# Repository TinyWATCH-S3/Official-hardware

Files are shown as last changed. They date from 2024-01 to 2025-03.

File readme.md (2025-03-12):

# TinyWATCH-S3 Official Hardware

In this repository, you will find all of the KiCAD design files for the official Unexpected Maker TinyWATCH-S3

**The current release version of the TinyWATCH S3 hardware is revision P10.**

Please note that the license for these design files is the CERN Open Hardware Licence v1.2, which requires any use of these design files to be also kept fully open source under the same license.

So though you are free to use these files in your own projects, and even commercialise them, the "thing" you make must be open source and shared with the community.

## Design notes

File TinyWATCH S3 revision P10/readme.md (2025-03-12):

# TinyWATCH-S3 revision P10

I've made my best efforts to ensure consistency between the PCB layout and Schematic in terms of component values and packages.

Many footprints in the design reference non-standard (library) footprints, and I don't offer a library for them as they are already embedded in PCB layout anyway. 

If you do find any other inconsistencies, please create a PR, or raise an issue, thanks :)

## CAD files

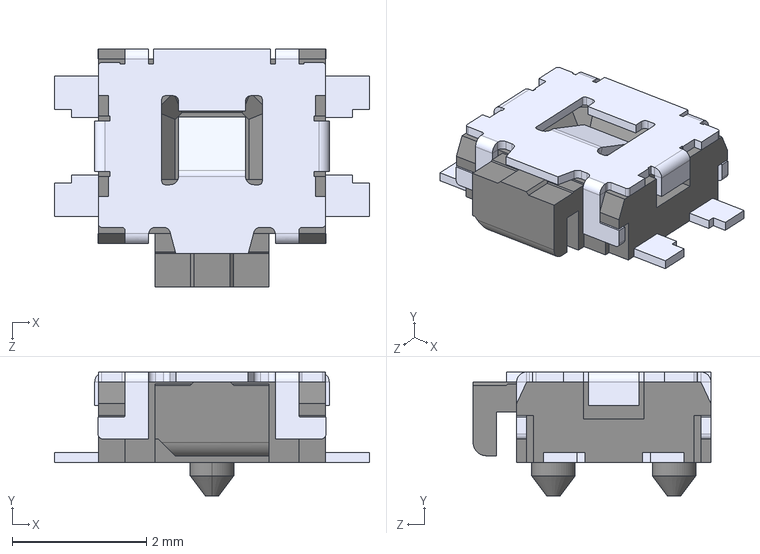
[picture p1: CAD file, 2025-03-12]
TinyWATCH S3 revision P10/KiCAD 8.09/3d_models/EVQ-P7C01P.step
4.70 x 1.85 x 3.55 mm

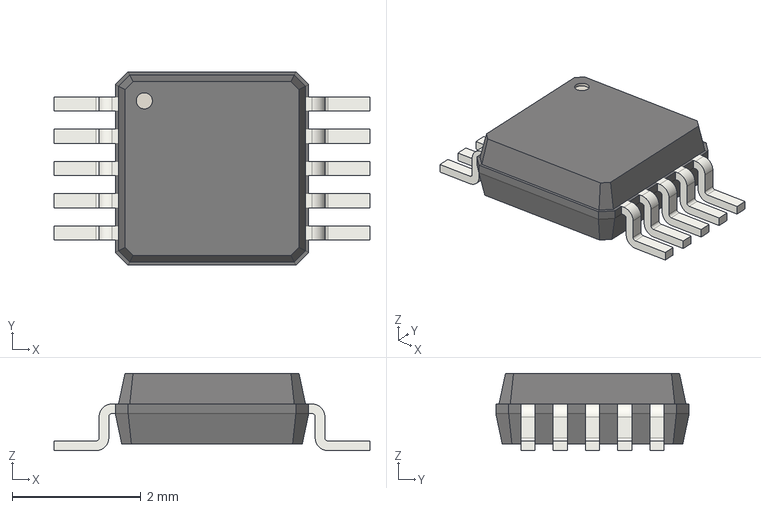
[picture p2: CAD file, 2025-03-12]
TinyWATCH S3 revision P7/KiCAD 8.09/3d_models/VSSOP-10_3x3mm_P0.5mm.step
4.90 x 3.00 x 1.20 mm

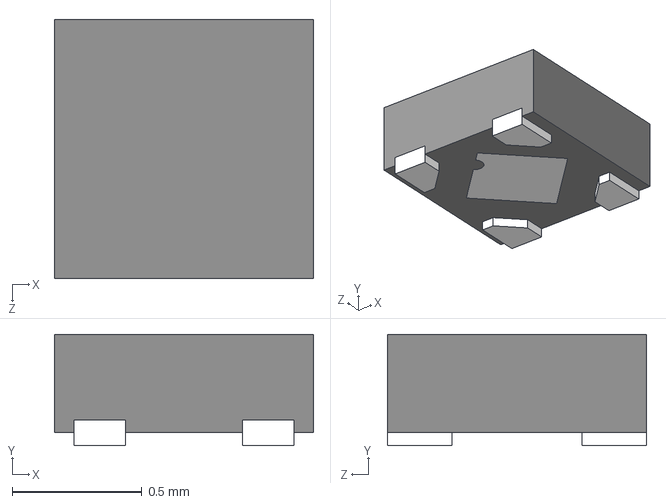
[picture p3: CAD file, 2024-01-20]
TinyWATCH S3 revision P7/KiCAD 8.09/3d_models/NCP170AMX170TCG.STEP
1.00 x 0.43 x 1.00 mm

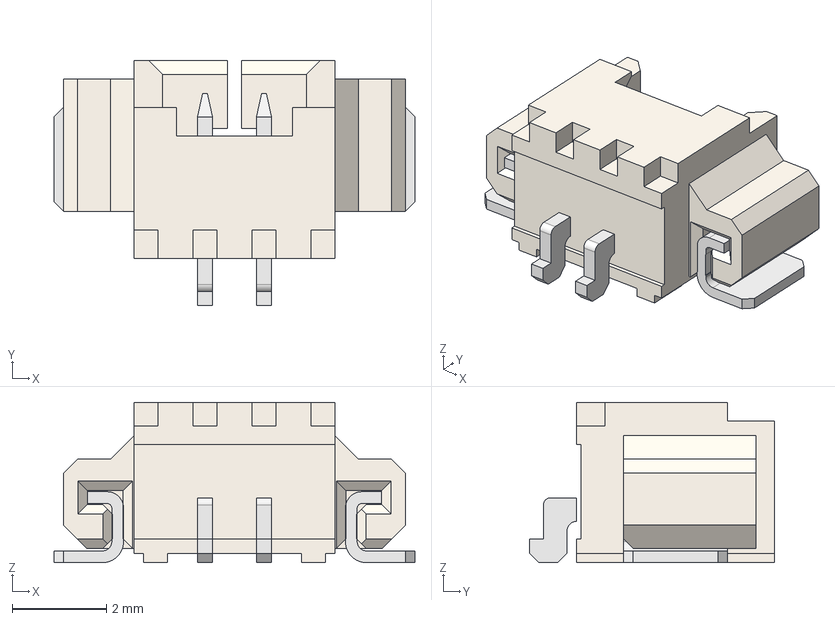
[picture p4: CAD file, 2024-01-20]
TinyWATCH S3 revision P7/KiCAD 8.09/3d_models/PICOBLADE Col v3.step
7.65 x 5.20 x 3.40 mm

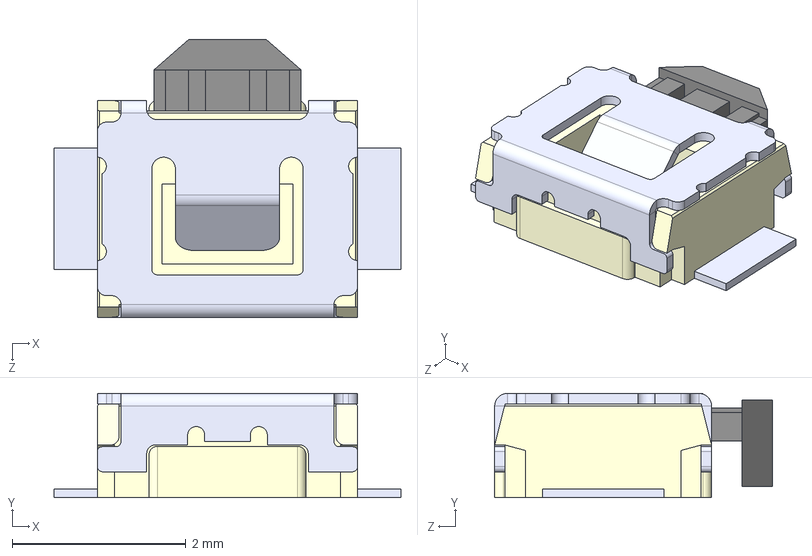
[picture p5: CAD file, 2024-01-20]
TinyWATCH S3 revision P10/KiCAD 8.09/3d_models/B3U-3000P--3DModel-STEP-56544.STEP
4.00 x 1.20 x 3.20 mm

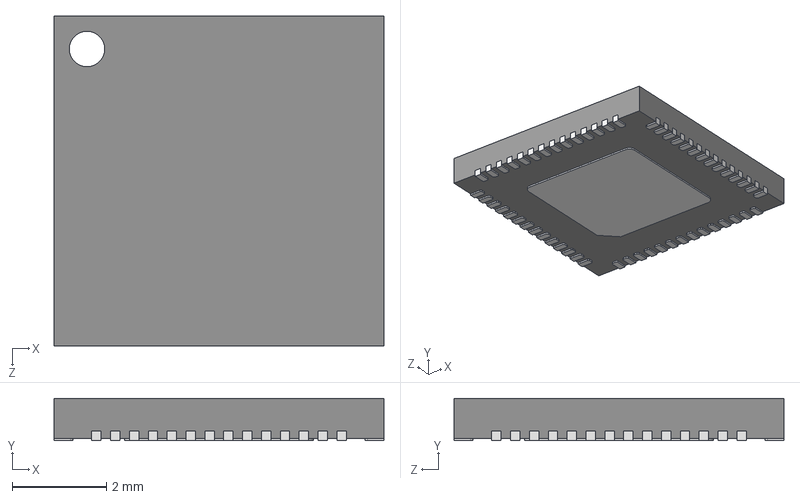
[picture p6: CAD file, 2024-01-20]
TinyWATCH S3 revision P7/KiCAD 8.09/3d_models/ESP32_S2--3DModel-STEP-1.STEP
7.00 x 0.9 x 7.00 mm

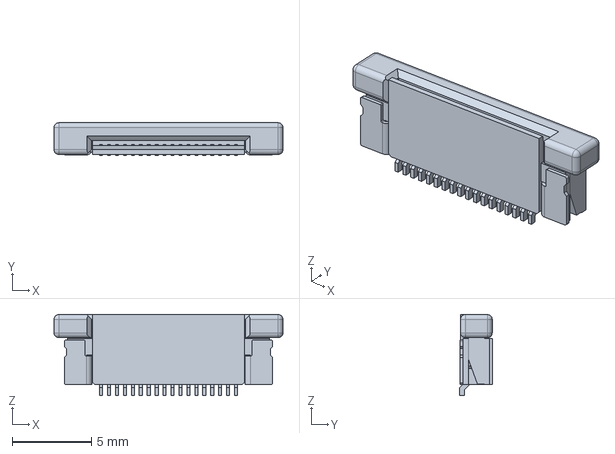
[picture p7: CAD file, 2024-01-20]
TinyWATCH S3 revision P10/KiCAD 8.09/3d_models/FPC_18pin_0.5mm_1-1734592-8.stp
14.4 x 2.05 x 5.11 mm

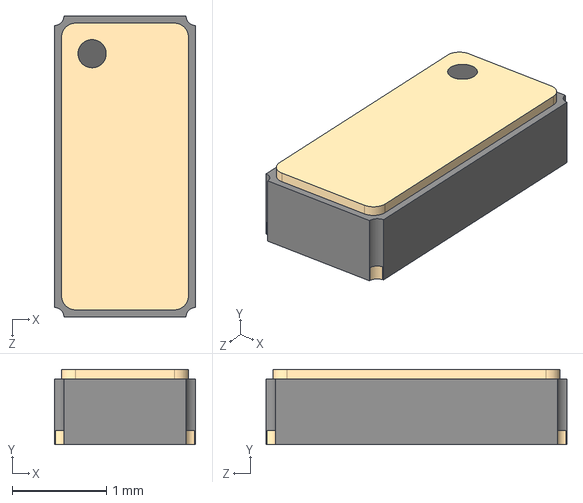
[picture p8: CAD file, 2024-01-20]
TinyWATCH S3 revision P7/KiCAD 8.09/3d_models/RV-3028-C7-32.768KHZ-1PPM-TA-QA.step
1.50 x 0.8 x 3.20 mm

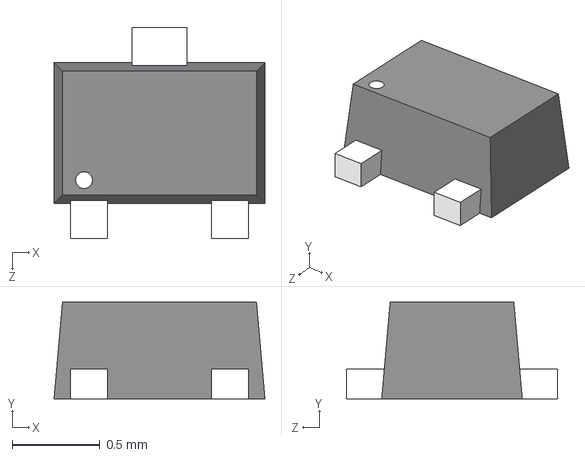
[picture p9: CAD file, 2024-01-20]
TinyWATCH S3 revision P10/KiCAD 8.09/3d_models/SOT-723.STEP
1.20 x 0.55 x 1.20 mm

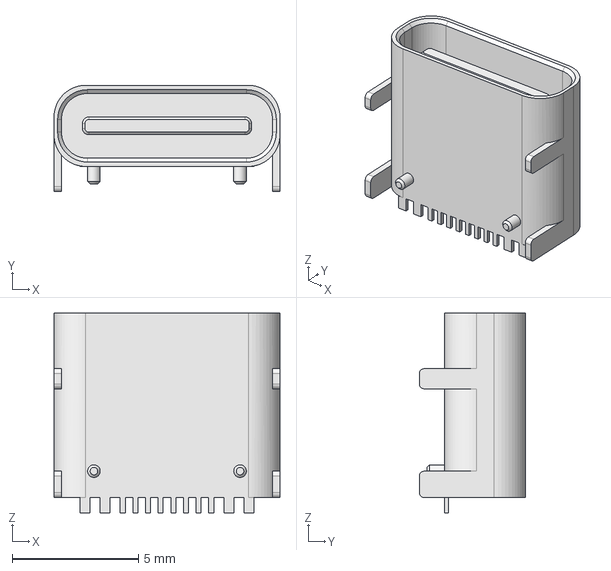
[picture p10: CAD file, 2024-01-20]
TinyWATCH S3 revision P10/KiCAD 8.09/3d_models/HRO USB-C col 3 v5.step
8.94 x 4.21 x 7.90 mm

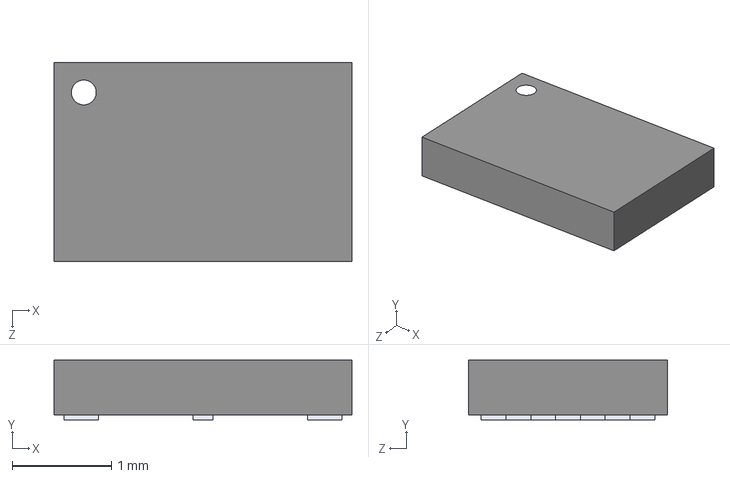
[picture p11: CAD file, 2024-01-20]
TinyWATCH S3 revision P10/KiCAD 8.09/3d_models/Flash_W25Q80DVUXIE.step
3.00 x 0.6 x 2.00 mm

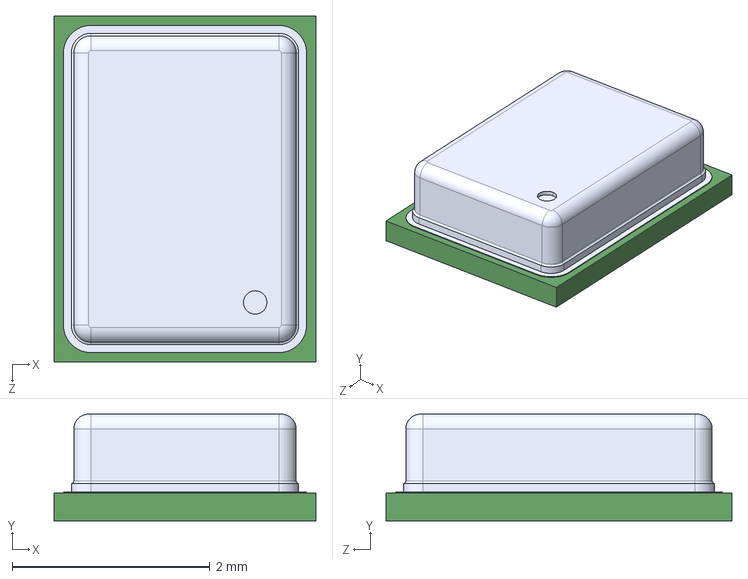
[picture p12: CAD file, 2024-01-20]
TinyWATCH S3 revision P7/KiCAD 8.09/3d_models/SPH0645LM4H-B--3DModel-STEP-56544.STEP
2.65 x 1.08 x 3.50 mm

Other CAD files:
TinyWATCH S3 revision P10/KiCAD 8.09/3d_models/SMD_Nut_M2.step

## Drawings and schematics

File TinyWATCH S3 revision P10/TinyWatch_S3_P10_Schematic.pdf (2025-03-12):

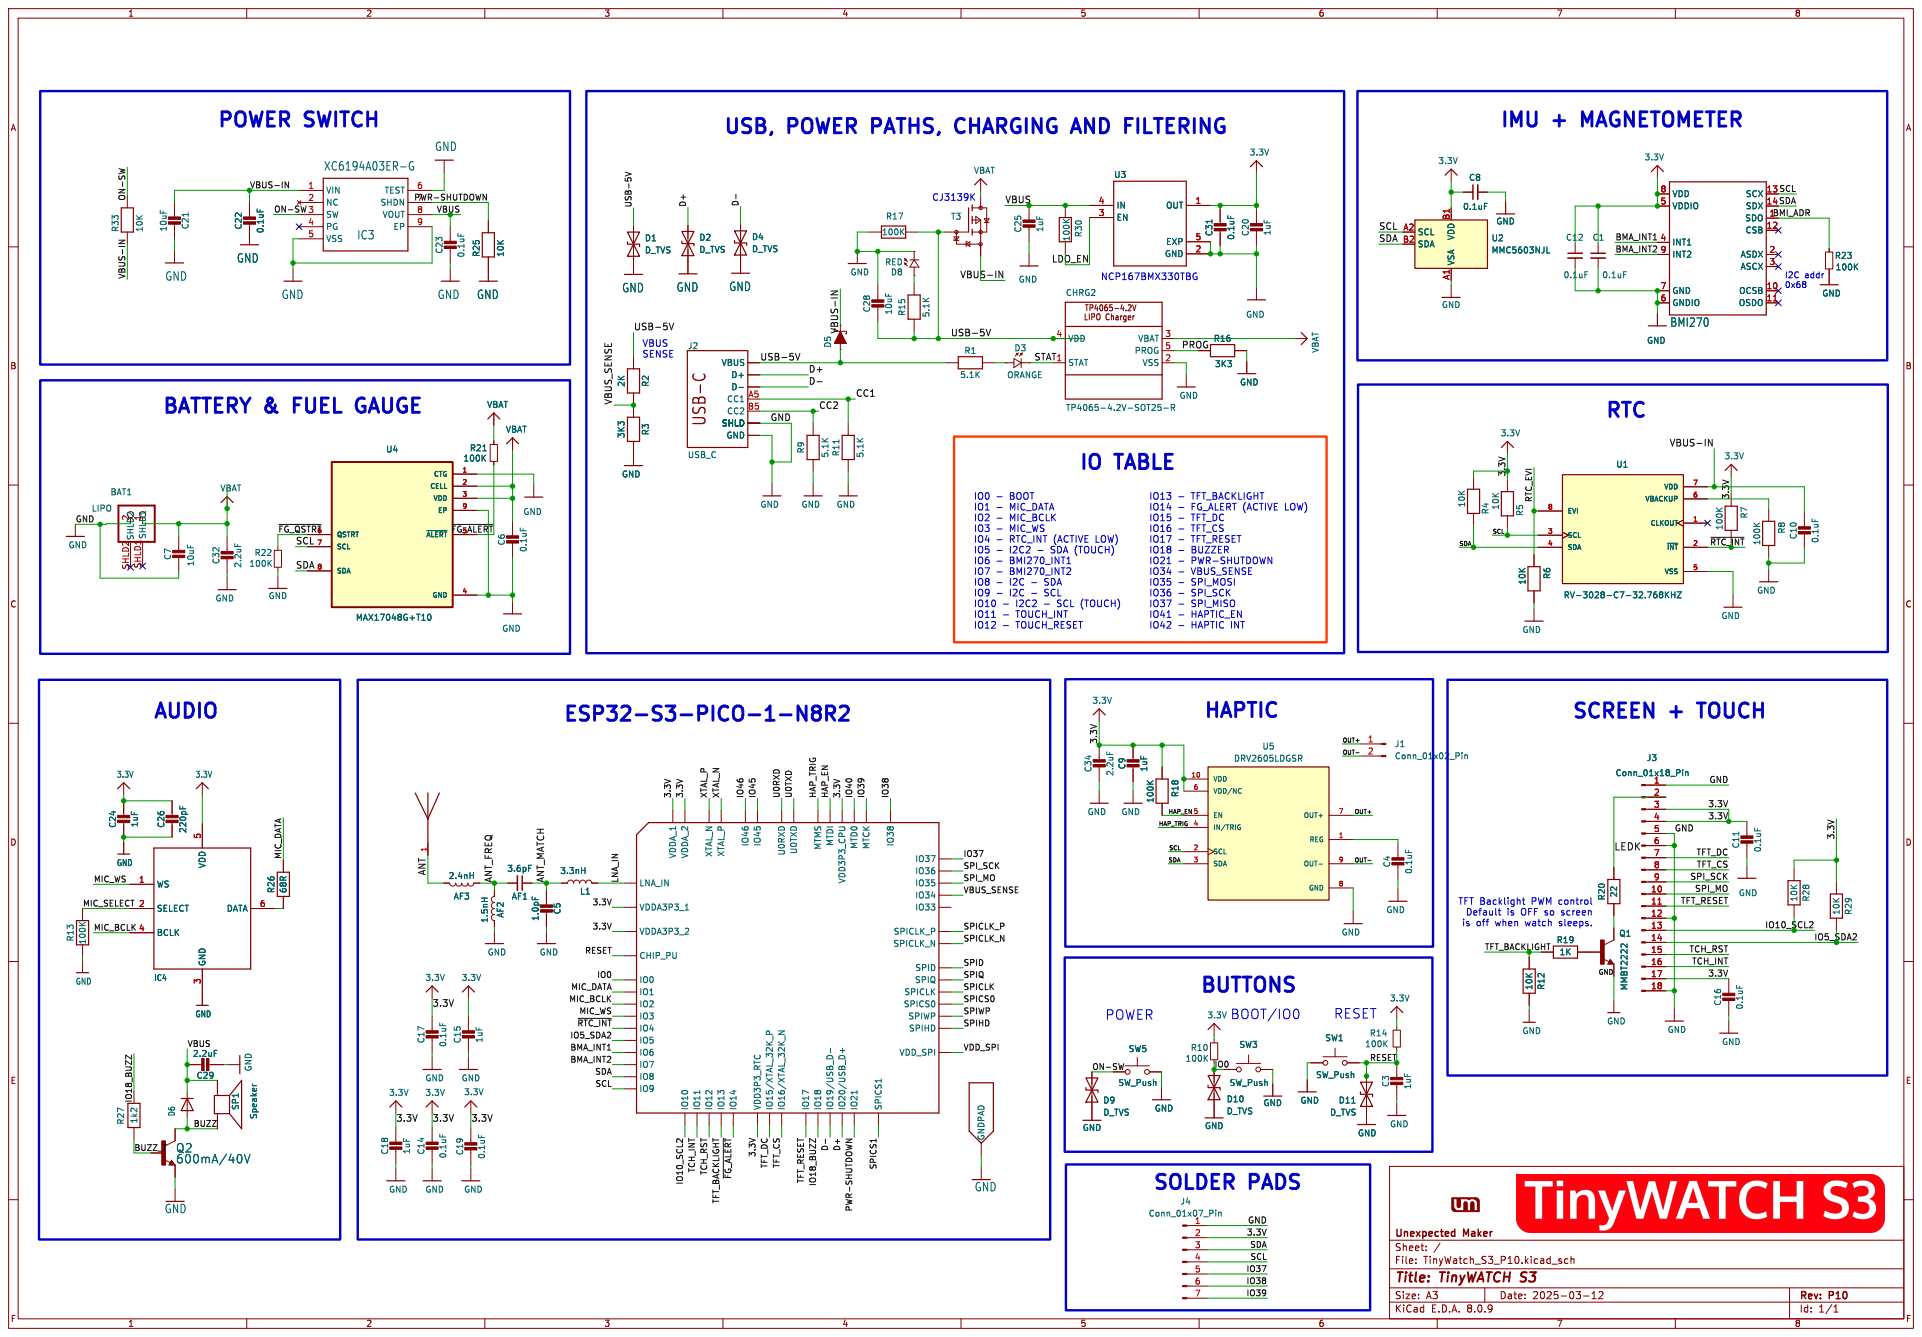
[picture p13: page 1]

IO12 - TOUCH_RESET CJ3139K USB, POWER PATHS, CHARGING AND FILTERING

VBUS-INON-SW ON-SW VBUS-IN

is off when watch sleeps.

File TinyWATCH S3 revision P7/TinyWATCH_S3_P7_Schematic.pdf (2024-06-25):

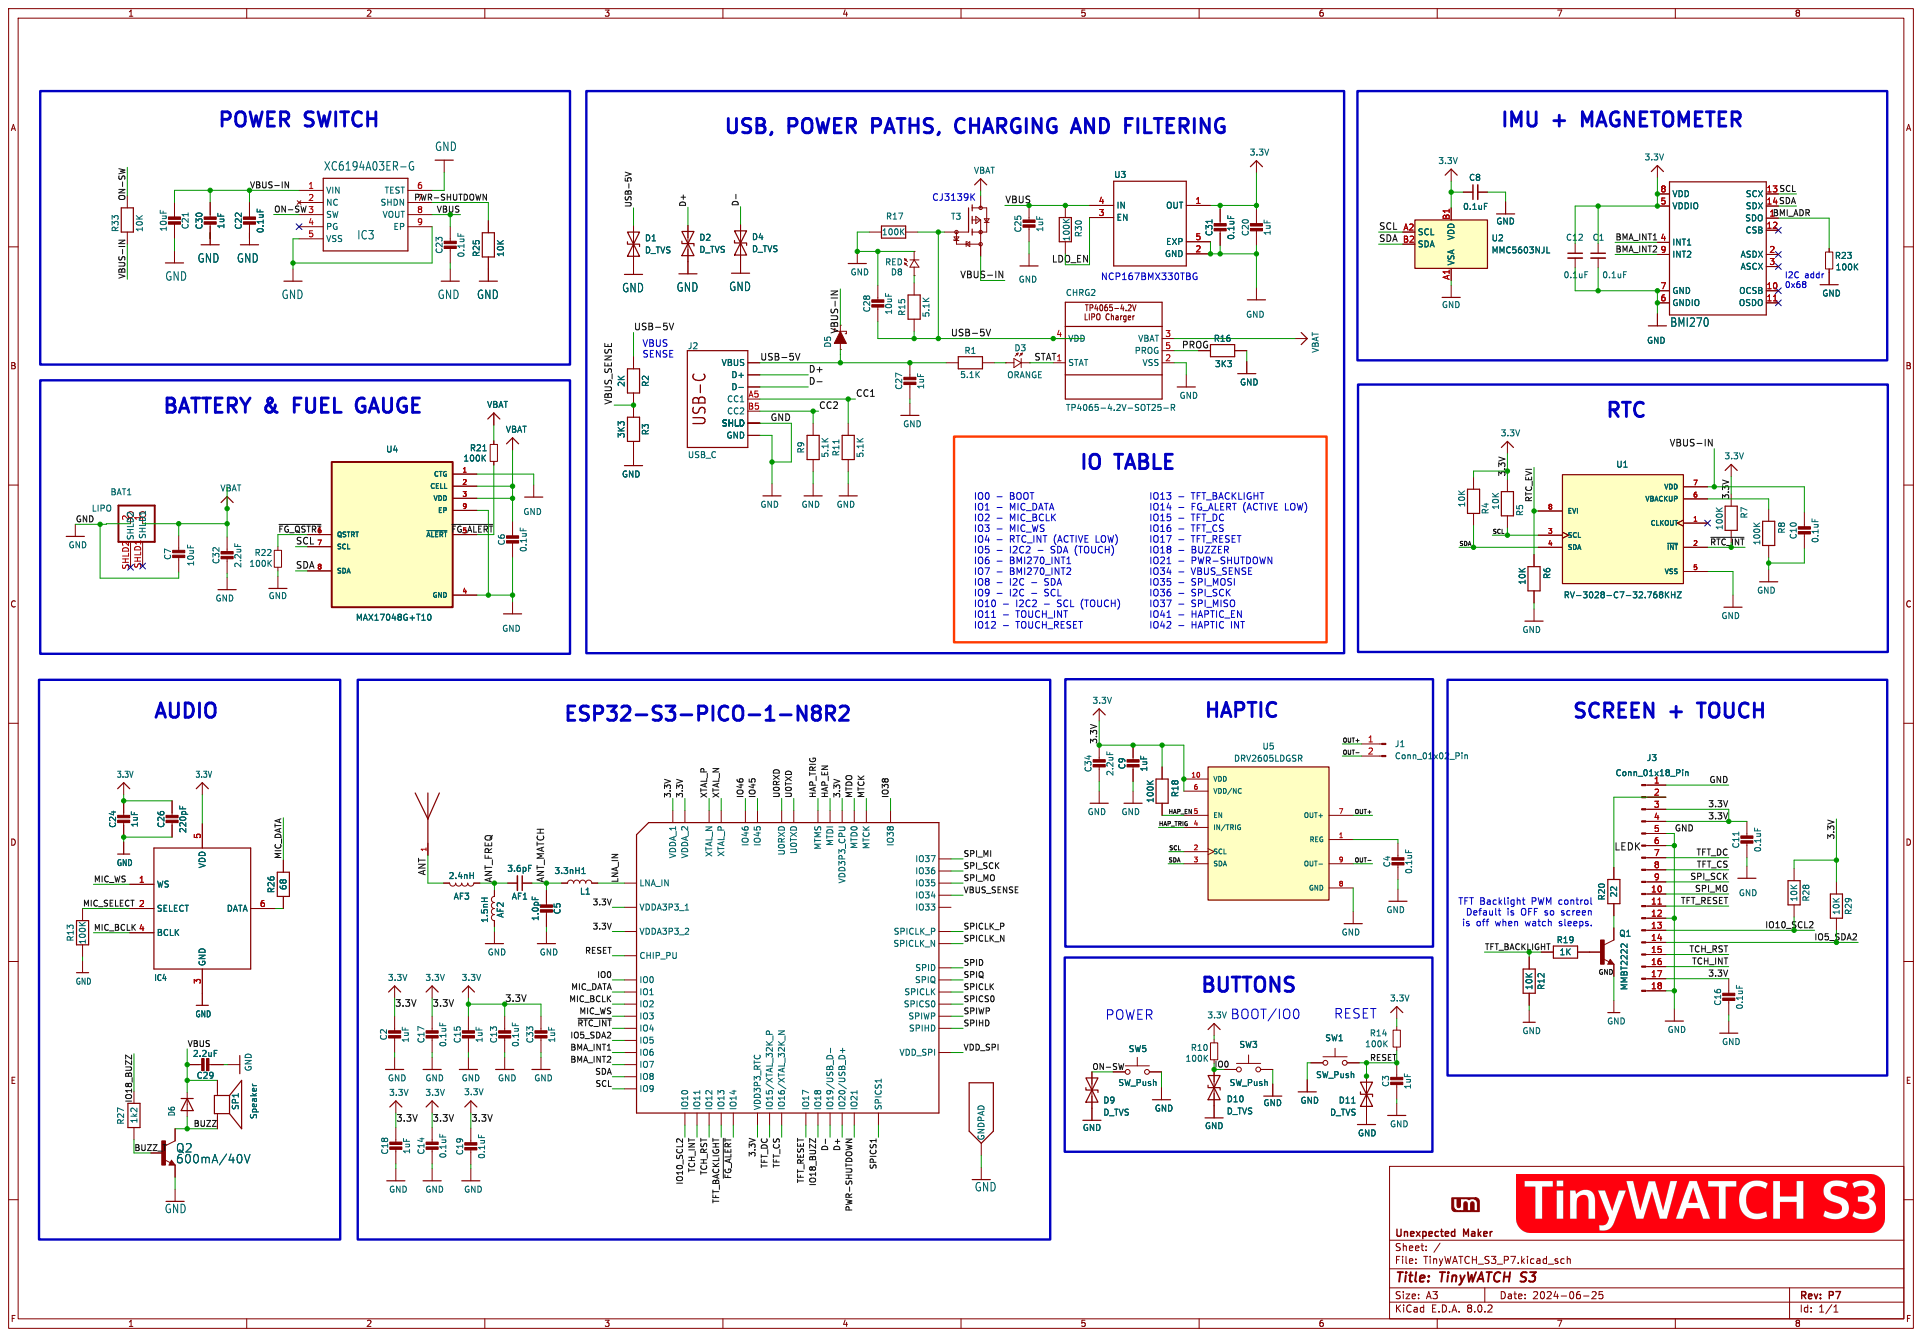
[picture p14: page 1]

USB, POWER PATHS, CHARGING AND FILTERING

is off when watch sleeps.

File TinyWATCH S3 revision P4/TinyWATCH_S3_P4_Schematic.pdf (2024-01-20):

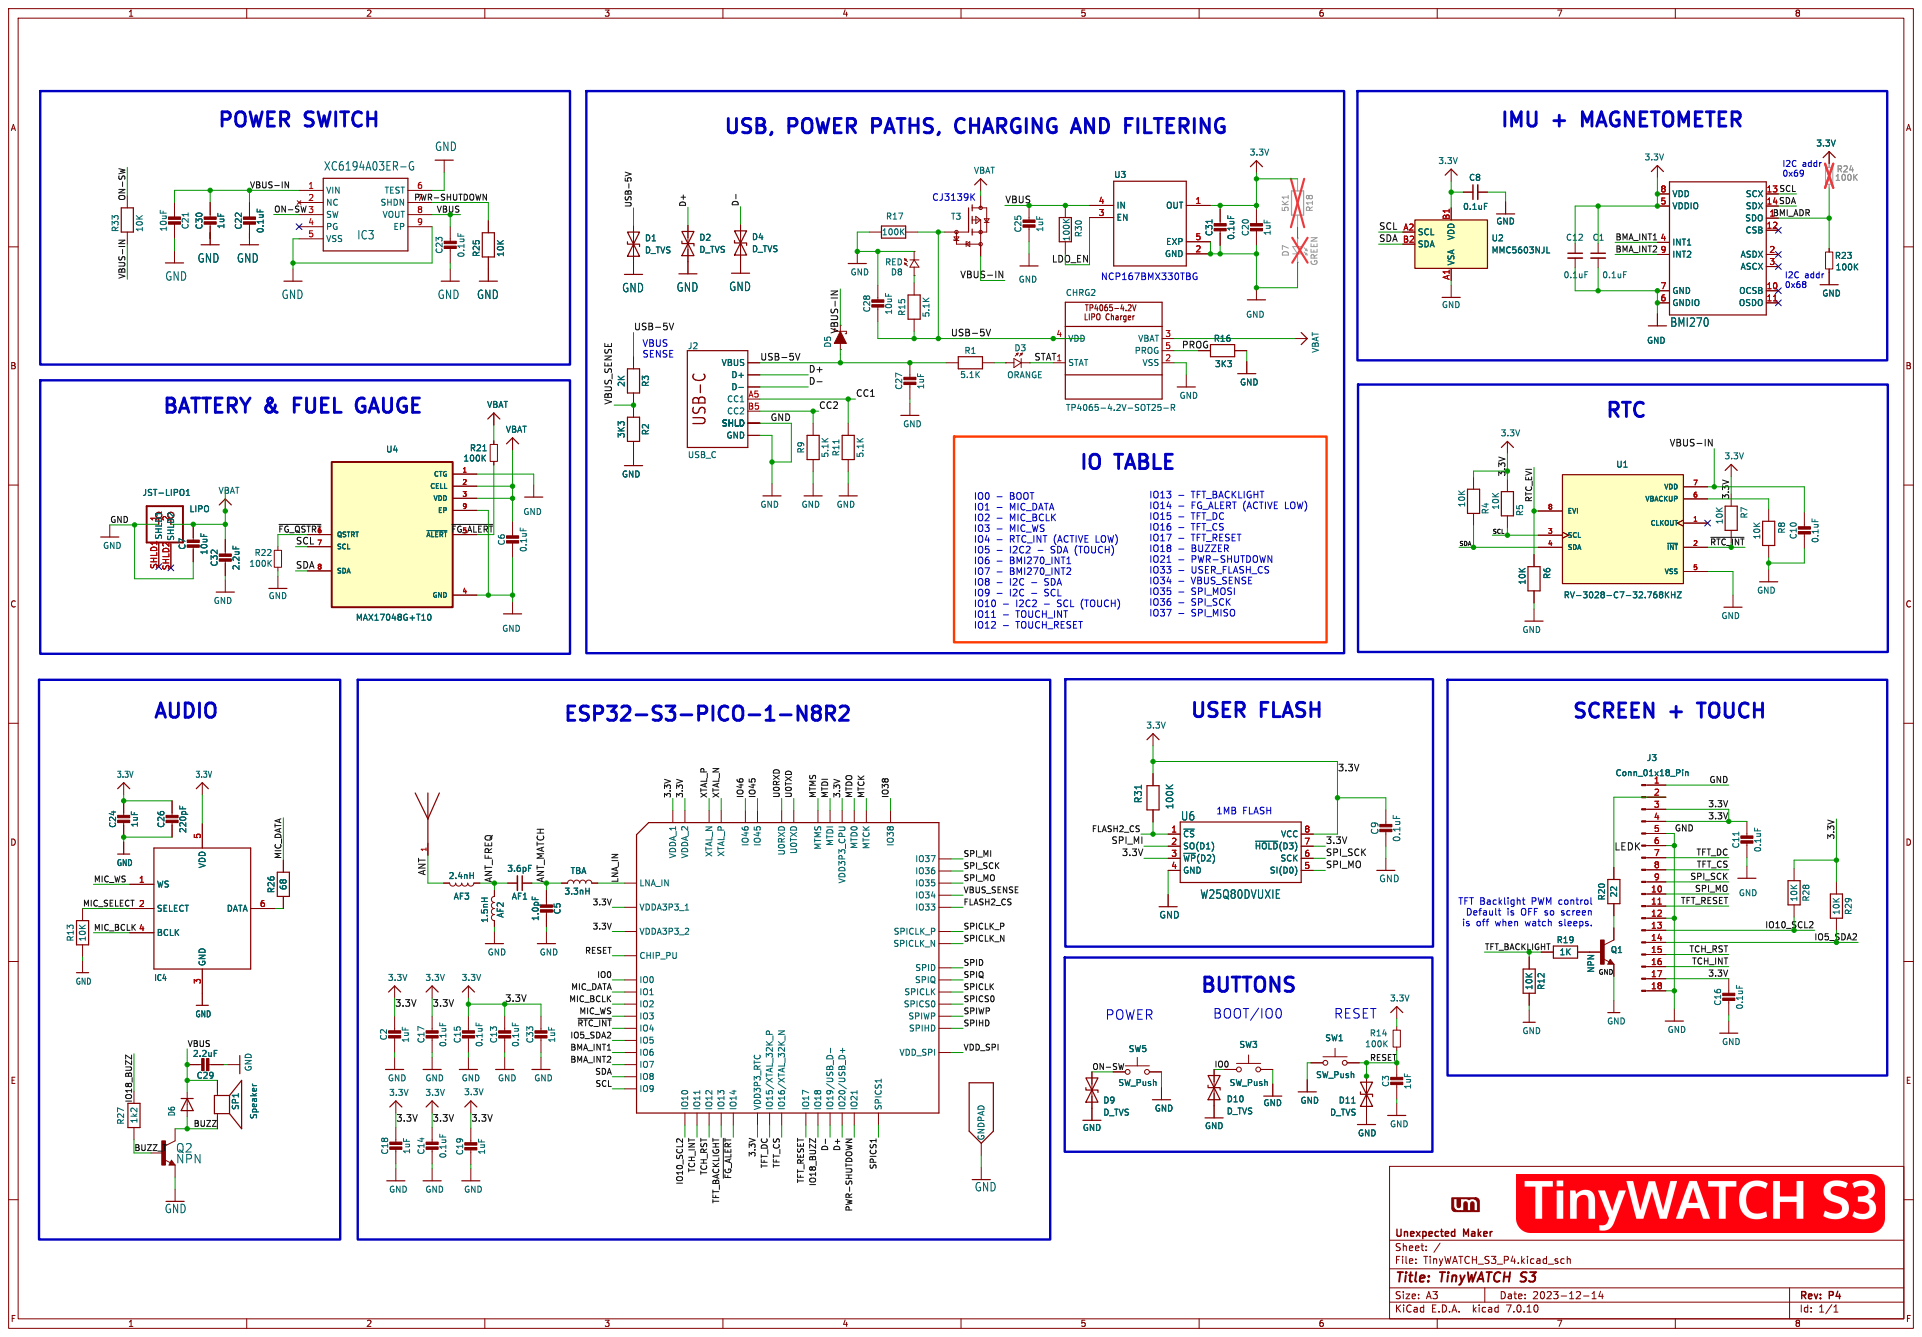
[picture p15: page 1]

3.3V ON-SW VBUS-IN

2 SHLD1 SHLD1SHLD2 SHLD2 C32 2.2uFC7 10uF U4 MAX17048G+T10 CTG 1 CELL 2 VDD 3 GND 4 ~{ALERT} 5 QSTRT 6 SCL 7 SDA 8 EP 9 VBATVBAT R21

is off when watch sleeps.

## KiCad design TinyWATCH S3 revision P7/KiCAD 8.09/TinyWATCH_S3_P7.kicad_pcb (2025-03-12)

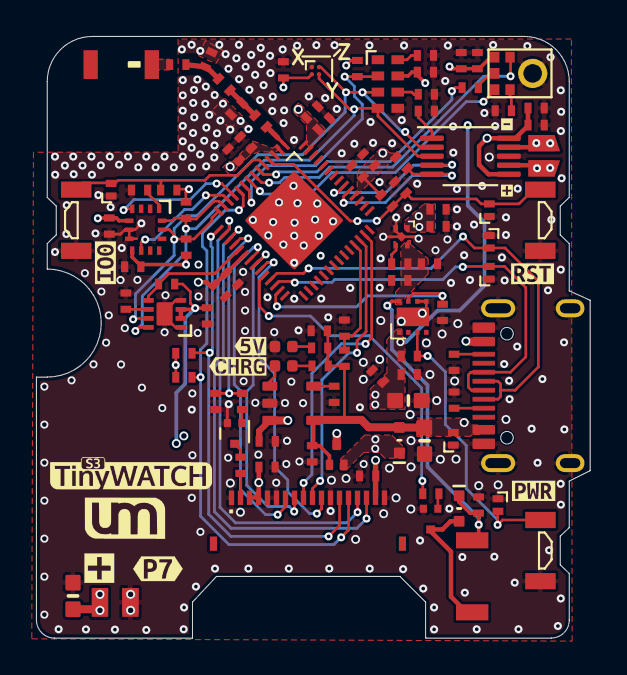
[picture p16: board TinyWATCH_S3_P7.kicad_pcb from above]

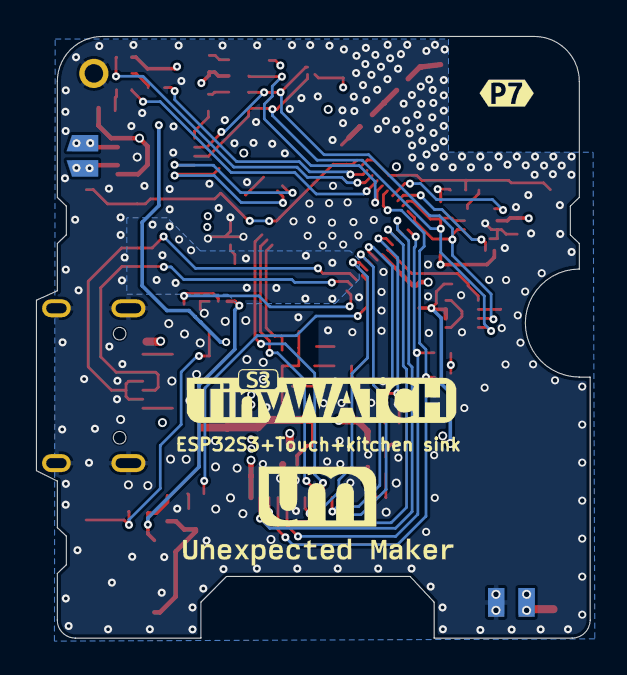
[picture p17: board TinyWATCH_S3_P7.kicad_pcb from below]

Board: 4 copper layers, 30.8 x 33.4 mm, 115 parts (3 on the bottom side), 60 nets.

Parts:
AF1: 3.6pF; _0402_SRN
AF2: 1.5nH; _0402_SRN
AF3: 2.4nH; _0402_SRN
BAT1: LIPO; HapticMotor_Solder_Pads
C1, C4, C6, C8, C10, C11, C12, C13, C14, C16, C17, C19, C22, C23, C31: 0.1uF; _0402_SRN
C2, C3, C9, C15, C18, C20, C24, C25, C27, C30, C33: 1uF; _0402_SRN
C5: 1.0pF; _0402_SRN
C7, C21, C28: 10uF; _0603MP
C26: 220pF; _0402_SRN
C29, C32, C34: 2.2uF; _0402_SRN
CHRG2: TP4065-4.2V-SOT25-R; SOT23-5-SML2
D1, D2, D4, D9, D10, D11: D_TVS; TVS X1-DFN1006-2-BEST
D3: ORANGE; LED_0402_1005Metric
D5: DIODE-SCHOTTKYWIDE; SOD-523-MSK4010
D6: DIODESOD-123; SOD-523-MSK4010
D8: RED; LED_0402_1005Metric
IC2: ESP32-S3REV0-SILICON; QFN56-ESP32-S3-PROD-THIN
IC3: XC6194AA03ER-G; XC6194BANNERG
IC4: ICS_43434; ICS43434
J1: Conn_01x02_Pin; HapticMotor_Solder_Pads
J2: USB_C; USB-C-16P-LESSPASTE-2-FIxed
J3: Conn_01x18_Pin; JUSHUO AFH34-S18FIA-1H
L1: 3.3nH; _0402_SRN
Q1: MMBT2222; SOT-723
Q2: 600mA/40V; SOT-723
R1, R9, R11, R15: 5.1K; _0402_SRN
R2: 2K; _0402_SRN
R3, R16: 3K3; _0402_SRN
R4, R5, R6, R12, R25, R28, R29, R33: 10K; _0402_SRN
R7, R8, R10, R13, R14, R17, R18, R21, R22, R23, R30: 100K; _0402_SRN
R19: 1K; _0402_SRN
R20: 22; _0402_SRN
R26: 68; _0402_SRN
R27: 1k2; _0402_SRN
SP1: Speaker; MagneticBuzzer_KLJ-4020
SW1, SW3, SW5: SW_Push; SW_SPST_B3U-3000P
T1, T1#2: Tab
T3: P-FET; SOT723
U1: RV-3028-C7-32.768KHZ; IC_RV-3028-C7-32.768KHZ-1PPM-TA-QA
U2: MMC5603NJL; WLP-4_0.83x0.83mm_P0.4mm
U3: NCP167BMX330TBG; VREG_NCP170AMX300TCG
U4: MAX17048G+T10; MAX17048G_T10_SON50P200X200X80-9N
U5: DRV2605LDGSR; VSSOP-10_3x3mm_P0.5mm
U$1: BMI270
U$13: FRACTUS_FR05-S1-N-0-102-LEAN; ANT_2450AT18B100E
U$88: UM_LOGONEW_SMALLER; UM_LOGO_NEW_TINY
U$88#2: UM_LOGONEW_SMALLER; UM_LOGO_NEW_SMALL
kibuzzard-64F95D11: G***; kibuzzard-64F95D11
kibuzzard-64F95D18: G***; kibuzzard-64F95D18
kibuzzard-65BEEB54: G***; kibuzzard-65BEEB54
kibuzzard-65BEEBBF: G***; kibuzzard-65BEEBBF
kibuzzard-65BF212E: G***; kibuzzard-65BF212E
kibuzzard-664EFB11: G***; kibuzzard-664EFB11
kibuzzard-664EFB60: G***; kibuzzard-664EFB60
kibuzzard-6518A76D: G***; kibuzzard-6518A76D
kibuzzard-6518A765: G***; kibuzzard-6518A765
kibuzzard-6534A245: G***; kibuzzard-6534A245
kibuzzard-664315DB: G***; kibuzzard-664315DB

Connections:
3.3V: C1.1, C2.1, C8.1, C9.1, C11.1, C12.1, C13.1, C14.1, C15.1, C16.1, C17.1, C18.1, C19.1, C20.1, C24.1, C26.1, C31.1, C33.1, C34.1, IC2.2 (VDDA3P3_1), IC2.3 (VDDA3P3_2), IC2.20 (VDD3P3_RTC), IC2.46 (VDD3P3_CPU), IC2.55 (VDDA_2), IC2.56 (VDDA_1), IC4.5 (VDD), J3.3, J3.4, J3.17, R4.1, R5.1, R7.1, R10.1, R14.1, R18.1, R28.1, R29.1, U2.B1 (VDD), U3.1 (OUT), U5.6 (VDD/NC), U5.10 (VDD), U$1.5 (VDDIO), U$1.8 (VDD)
/ANT: AF3.2, U$13.1
/ANT_FREQ: AF1.2, AF2.2, AF3.1
/ANT_MATCH: AF1.1, C5.2, L1.1
/BMA_INT1: IC2.11 (IO6), U$1.4 (INT1)
/BMA_INT2: IC2.12 (IO7), U$1.9 (INT2)
/BMI_ADR: R23.1, U$1.1 (SDO)
/BUZZ: D6.A, Q2.3 (C), SP1.-
/BUZZ_T: Q2.1 (B), R27.1
/CC1: J2.A5 (CC1), R11.2
/CC2: J2.B5 (CC2), R9.2
/D+: D2.2 (A2), IC2.26 (IO20/USB_D+), J2.A6 (D+), J2.B6 (D+)
/D-: D4.2 (A2), IC2.25 (IO19/USB_D-), J2.A7 (D-), J2.B7 (D-)
/HAP_EN: IC2.47 (MTDI), R18.2, U5.5 (EN)
/HAP_TRIG: IC2.48 (MTMS), U5.4 (IN/TRIG)
/IO0: D10.2 (A2), IC2.5 (IO0), R10.2, SW3.2
/IO5_SDA2: IC2.10 (IO5), J3.14, R29.2
/IO10_SCL2: IC2.15 (IO10), J3.13, R28.2
/IO18_BUZZ: IC2.24 (IO18), R27.2
/LDO_EN: R30.2, U3.3 (EN)
/LEDK: J3.2, R20.2
/LNA_IN: IC2.1 (LNA_IN), L1.2
/MIC_BCLK: IC2.7 (IO2), IC4.4 (BCLK)
/MIC_DATA: IC2.6 (IO1), R26.2
/MIC_SELECT: IC4.2 (SELECT), R13.2
/MIC_WS: IC2.8 (IO3), IC4.1 (WS)
/ON-SW: D9.2 (A2), IC3.3 (SW), R33.1, SW5.1
/OUT+: J1.1, U5.7 (OUT+)
/OUT-: J1.2, U5.9 (OUT-)
/PROG: CHRG2.5 (PROG), R16.1
/PWR-SHUTDOWN: IC2.27 (IO21), IC3.7 (SHDN), R25.1
/RESET: C3.1, D11.2 (A2), IC2.4 (CHIP_PU), R14.2, SW1.1
/RTC_EVI: R6.1, U1.8 (EVI)
/SCL: IC2.14 (IO9), R5.2, U1.3 (SCL), U2.A2 (SCL), U4.7 (SCL), U5.2 (SCL), U$1.13 (SCX)
/SDA: IC2.13 (IO8), R4.2, U1.4 (SDA), U2.B2 (SDA), U4.8 (SDA), U5.3 (SDA), U$1.14 (SDX)
/SPI_MO: IC2.40 (IO35), J3.10
/SPI_SCK: IC2.41 (IO36), J3.9
/STAT: CHRG2.1 (STAT), D3.P$2 (2)
/TCH_INT: IC2.16 (IO11), J3.16
/TCH_RST: IC2.17 (IO12), J3.15
/TFT_BACKLIGHT: IC2.18 (IO13), R12.1, R19.1
/TFT_CS: IC2.22 (IO16/XTAL_32K_N), J3.8
/TFT_DC: IC2.21 (IO15/XTAL_32K_P), J3.7
/TFT_RESET: IC2.23 (IO17), J3.11
/USB-5V: C27.1, C28.2, CHRG2.4 (VDD), D1.2 (A2), D5.A, J2.VBUS1 (VBUS), J2.VBUS2 (VBUS), R1.1, R2.1, R15.1, R17.1, T3.1 (G)
/VBUS: C23.1, C25.1, C29.1, D6.C, IC3.8 (VOUT), R30.1, SP1.+, U3.4 (IN)
/VBUS-IN: C10.1, C21.2, C22.1, C30.1, D5.C, IC3.1 (VIN), R33.2, T3.2 (S), U1.7 (VDD)
/VBUS_SENSE: IC2.39 (IO34), R2.2, R3.1
/~FG_ALERT: IC2.19 (IO14), R21.2, U4.5 (~ALERT)
/~FG_QSTRT: R22.1, U4.6 (QSTRT)
/~RTC_INT: IC2.9 (IO4), R7.2, U1.2 (~INT)
GND: AF2.1, BAT1.2, C1.2, C2.2, C3.2, C4.2, C5.1, C6.2, C7.2, C8.2, C9.2, C10.2, C11.2, C12.2, C13.2, C14.2, C15.2, C16.2, C17.2, C18.2, C19.2, C20.2, C21.1, C22.2, C23.2, C24.2, C25.2, C26.2, C27.2, C28.1, C29.2, C30.2, C31.2, C32.2, C33.2, C34.2, CHRG2.2 (VSS), D1.1 (A1), D2.1 (A1), D4.1 (A1), D8.P$2 (2), D9.1 (A1), D10.1 (A1), D11.1 (A1), IC2.EXP (GNDPAD), IC3.5 (VSS), IC3.6 (TEST), IC3.9 (EP), IC4.3 (GND), J2.GND, J2.GND2 (GND), J2.SHLD, J3.1, J3.5, J3.6, J3.12, J3.18, Q1.2 (E), Q2.2 (E), R3.2, R6.2, R8.2, R9.1, R11.1, R12.2, R13.1, R16.2, R17.2, R22.2, R23.2, R25.2, SW1.2, SW3.1, SW5.2, U1.5 (VSS), U2.A1 (VSA), U3.2 (GND), U3.5 (EXP), U4.1 (CTG), U4.4 (GND), U4.9 (EP), U5.8 (GND), U$1.6 (GNDIO), U$1.7 (GND)
unnamed: C4.1, U5.1 (REG)
unnamed: D3.P$1 (1), R1.2
unnamed: D8.P$1 (1), R15.2
unnamed: IC4.6 (DATA), R26.1
unnamed: Q1.1 (B), R19.2
unnamed: Q1.3 (C), R20.1
unnamed: R8.1, U1.6 (VBACKUP)
VBAT: BAT1.1, C6.1, C7.1, C32.1, CHRG2.3 (VBAT), R21.1, T3.3 (D), U4.2 (CELL), U4.3 (VDD)

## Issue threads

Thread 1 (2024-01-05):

Battery Specs - Looking to confirm one that will work

KenSamson, 2024-01-05:
Looking to confirm if this would work.   I also need to verify polarity... my physical watch should arrive next week...

EEMB Lithium Polymer Battery 3.7V 250mAh 502030 Lipo Rechargeable Battery Pack with Wire JST 2.0mm Connector for VXI Blue Parrott- Confirm Device & Connector Polarity Before Purchase
[Visit the EEMB Store](https://www.amazon.com/stores/EEMB/page/658058FE-9FB9-45FD-B882-BDFC4A2D3C9F?ref_=ast_bln)

UnexpectedMaker, 2024-01-05:
The connector you need is  1.25mm, not 2mm JST.
This is the battery I am currently experimenting with. It's a tad thicker, and might ned a case tweak, but it's the biggest capacity I can find in a small package as is narrower then other's I've looked at.
https://s.click.aliexpress.com/e/_DkbJJYp

It also has the correct polarity for guidance, but you can always swap the wires in the connector if you are careful.

dcoles, 2024-01-27:
I have a [400 mAh PKCELL LP801735](https://cdn-shop.adafruit.com/product-files/3898/3898_specsheet_LP801735_400mAh_3.7V_20161129.pdf) ([adafruit](https://www.adafruit.com/product/3898)) which is *almost* the perfect size, but just a fraction too thick (about 1 mm out of the backing recess). I might have to bust out the Dremel.

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

<details>
<summary>Top-down</summary>

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

</details>

<details>
<summary>Official Dimensions</summary>

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

</details>

UnexpectedMaker, 2024-01-27:
Yeah, 8mm is a bit thick for mu case design.
You can just alter the back of the case STEP file to make it deeper, and re-print it, if you have a 3D printer.... or Dremel it ;)

My case design was based around 3-4mm thick batteries.

UnexpectedMaker, 2024-01-27:
Oh, the pink foam needs to bake taken out. It's only there for when there is no battery, to keep the PCB in place.
If you are worried about protecting the battery/electronics, you'll want to find something thinner than the foam, or I guess you could use it, but it's going to make for a very thick watch ;)

dcoles, 2024-01-27:
> Oh, the pink foam needs to bake taken out. It's only there for when there is no battery

Got it! I just included the foam in the photos for scale.

> or I guess you could use it, but it's going to make for a very thick watch ;)

Hey, it [worked for Dick Tracy](https://github.com/TinyWATCH-S3/Official-hardware/assets/1007415/d14568c1-c52a-4f70-a9b9-dde94edad37a). XD

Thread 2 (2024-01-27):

"JST" battery header confusion

dcoles, 2024-01-27:
My TinyWATCH arrived today (thank you for the quick shipping!), but I'm a little confused which battery connector is on the PCB.

The [IBOM](https://github.com/TinyWATCH-S3/Official-hardware/blob/main/TinyWATCH%20S3%20revision%20P4/ibom/ibom.html) lists it as a "2P-MICROBLADE" with a "JST-PICOBLADE" footprint, while the [KiCAD schematic](https://github.com/TinyWATCH-S3/Official-hardware/blob/main/TinyWATCH%20S3%20revision%20P4/KiCAD%207.0.10/TinyWATCH_S3_P4.kicad_pcb) says it's a "2-Pin JST PH Series Right-Angle Connector", though it's too small for any of my existing my existing LiPo batteries with 2mm JST PH connectors.

I'm pretty sure it's a [Molex PicoBlade](https://www.mouser.com/new/molex/molex-picoblade/) given the 1.25mm pitch.

I somehow lucked out already having a box of [Molex PicoBlade "compatible" connectors](https://www.amazon.com/1-25mm-Connectors-Pre-Crimped-Pixhawk-Silicone/dp/B07S18D3RN/). It's a bit of a tight fit behind the magnetic buzzer, but mates quite snugly.

UnexpectedMaker, 2024-01-27:
Fixed, thanks!

Closed 2024-01-27.

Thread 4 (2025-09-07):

Hardware feedback

Dominaezzz, 2025-09-07:
Great product! Makes me want to actually use an ESP32-S3 as a smart watch.

I just wanted to say that if you make another version of this device, some of the pin choices could be improved.
In particular, I2C, interrupt pins and xtal clock for low power bluetooth.

See https://github.com/Dominaezzz/Optimal-Development-Board-Guides/blob/main/ESP32-S3.md for details.

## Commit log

2024-01-20 Updated Schematic PDF Added KiCAD 7.0.10 design files Added ibom output
    [TinyWATCH_S3_P4.kicad_pcb, TinyWATCH_S3_P4.kicad_sch]
2024-01-20 Updated and added new readme cleaned up footprint naming
    [TinyWATCH_S3_P4.kicad_pcb, TinyWATCH_S3_P4.kicad_sch]
2024-01-20 Added KiCAD project file
2024-01-20 added 3d models that were referenced externally
    [B3U-3000P--3DModel-STEP-56544.STEP, ESP32_S2--3DModel-STEP-1.STEP, FPC_18pin_0.5mm_1-1734592-8.stp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]
2024-01-27 fixed MICRO/PICO Blade connector footrint description
    [TinyWATCH_S3_P4.kicad_pcb, TinyWATCH_S3_P4.kicad_sch]
2025-03-12 Added P7 files for KiCAD Added P10 files for KiCAD
    [B3U-3000P--3DModel-STEP-56544.STEP, ESP32_S2--3DModel-STEP-1.STEP, EVQ-P7C01P.step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]

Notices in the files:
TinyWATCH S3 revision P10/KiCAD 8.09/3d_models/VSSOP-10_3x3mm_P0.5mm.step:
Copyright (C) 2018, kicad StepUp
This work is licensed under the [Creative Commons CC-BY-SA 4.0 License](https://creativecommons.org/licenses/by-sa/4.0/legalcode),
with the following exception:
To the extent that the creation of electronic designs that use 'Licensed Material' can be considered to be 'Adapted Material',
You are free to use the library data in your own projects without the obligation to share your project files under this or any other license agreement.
